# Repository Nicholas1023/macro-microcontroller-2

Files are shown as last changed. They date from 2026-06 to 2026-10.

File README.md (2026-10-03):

# Macro Microcontroller 2

An RP2040 microcontroller development board with an integrated macropad that lets you control GPIOs with keyboard keys on a single PCB, plus a custom BASIC interpreter and disk operating system.

Documentation page: <a href="https://nicholaslim.me/macro-microcontroller-2">https://nicholaslim.me/macro-microcontroller-2</a>

Hack Club Stardance Challenge project: <a href="https://stardance.hackclub.com/projects/21502">https://stardance.hackclub.com/projects/21502</a>

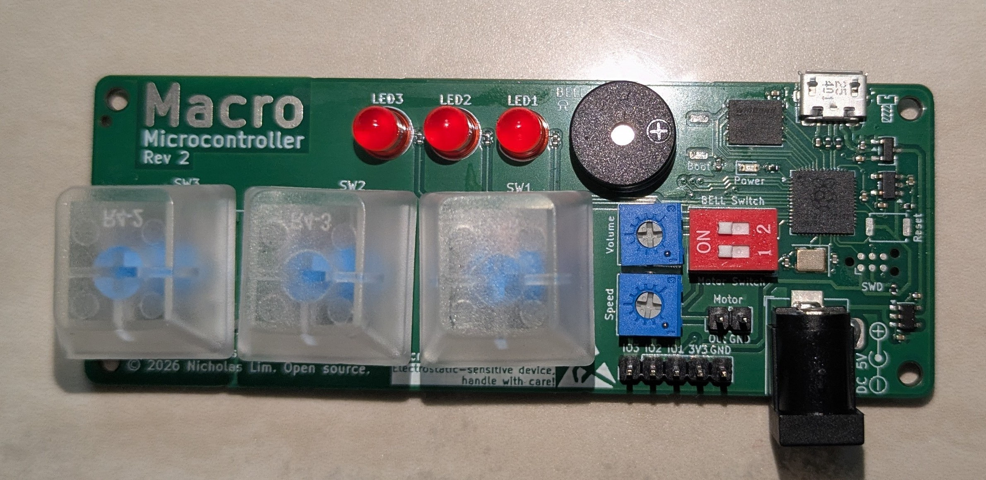
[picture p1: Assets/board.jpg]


View hardware demonstration at <a href="https://nicholaslim.me/macro-microcontroller-2/assets/hardware-demo.mp4">https://nicholaslim.me/macro-microcontroller-2/assets/hardware-demo.mp4</a>!

## What's New?
1. Microcontroller unit directly soldered on board!
2. More output devices with speed and volume adjustments (Buzzer and motor).
3. More ways to power the board (Barrel jack, USB, GPIO pins).
4. Custom BASIC interpreter and a disk operating system.

## What Does it Do?
Macro Microcontroller 2 allows you to control GPIO pins using macropad-like keys and from the serial terminal using the built-in <a href="Firmware Files/macro-microcontroller-basic.c">Macro Microcontroller BASIC Interpreter</a> or a <a href="Firmware Files/macro-microcontroller-bios+dos.c">disk operating system</a> for simple uses. It offers more ways to control GPIOs by having builtin keys that can be programmed to your own needs.

## Enclosure
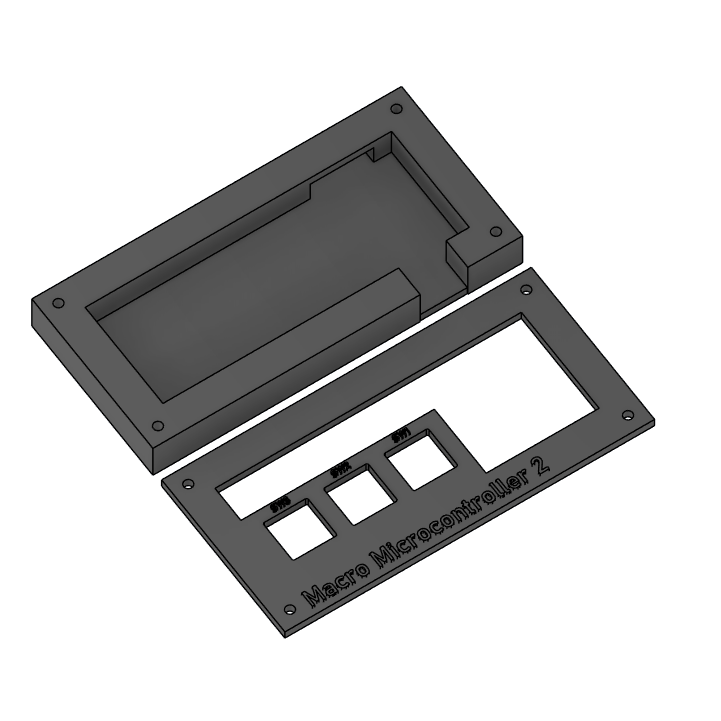
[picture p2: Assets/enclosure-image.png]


## Datasheet
For more details on the hardware, please read the <a href="docs/assets/macro-microcontroller-2-datasheet.pdf">datasheet</a>!

## Firmware
### Macro Microcontroller BIOS
A basic BIOS-like firmware, which performs basic POST routines and reports information on the device. <a href="Firmware Files/macro-microcontroller-bios.c">Source code</a>.
```
 _  _
| \/ | Macro Microcontroller BIOS Version 0.0.2.
|_\/_| Copyright (C) 2025-2026 Nicholas Lim.

Device: Macro Microcontroller 2 (RP2040 @ 125MHz)
Serial Number: ****************
RAM Free: 254K OK
Serial Status: Connected

Press SW1 to enter Macro Microcontroller BASIC.
Press SW2 to enter BOOTSEL mode.

Booting system...
```

### Macro Microcontroller DOS
A simple DOS-like environment that boots from the BIOS. <a href="Firmware Files/macro-microcontroller-bios+dos.c">Source code</a>.

Available commands (* denotes optional parameters):
1. `HELP`: Launches the help guide.
2. `CALCULATE`: Performs basic operations on 2 numbers. Usage: `CALCULATE [Number] [+ - * / ^ root] [Number]`
3. `ECHO`: Echoes text.
4. `PROGLIST`: Show program listing.
5. `SYSTEM`: Starts another Macro Microcontroller DOS console.
6. `EXIT`: Stops all processes for power off.
7. `OUT`: Turns on a specified GPIO for 1 second. Usage: `OUT [LED# IO# BELL MOTOR]`
8. `VERSION`: Shows the release version.
9. `BOOT`: Reboots the system. Usage: `BOOT -m [BASIC BOOTSEL]*`
10. `DEVINFO`: Displays device and memory information.
11. `UPTIME`: Shows device uptime.

### Macro Microcontroller BASIC Interpreter
A BASIC interpreter written in C for Macro Microcontroller, providing a simple coding environment via a serial terminal. You may view a demo at <a href="Assets/firmware-demo.mp4">Assets/firmware-demo.mp4</a>.

Currently available statements:
1. `PRINT`: Outputs text to the serial terminal.
2. `LET`: Assigns a value (integer, float or string) to a variable (Only one variable is allowed for now).
3. `INPUT`: Assigns a value (integer, float or string) to a variable via user input.
4. `GPIO`: Turns on a specified GPIO pin for 1 second.
5. `LSVAR`: Outputs variable name and their value to the serial terminal.
6. `END`: Clears variable and reset line numbers.
7. `EXIT`: Puts the device into sleep/power off mode.
8. `KEY`: Pass GPIO controls to the macropad.
9. `REM`: Add comments to your program.

For example programs, see <a href="Firmware Files/example.bas">Firmware Files/example.bas</a>.
Try out the web editor at <a href="https://editor.nicholaslim.me/macro-microcontroller">https://editor.nicholaslim.me/macro-microcontroller</a>!

## Schematics


View PCB file at https://kicanvas.org/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!

## Repository Structure
```
main
 ├── /docs ← Documentation website and datasheet files are here
 ├── /Assets ← Images and videos are here
 │     └── /Journal ← Images for JOURNAL.md
 ├── /PCB Files ← .kicad_ files are here
 ├── /Production Files ← Gerber and BOM files are here
 ├── /Printing Files ← STLs are here
 ├── /Firmware Files ← Firmware files are here
 ├── JOURNAL.md ← Devlogs
 ├── README.md ← This file
 ├── LICENSE.txt ← License
 └── schematics.pdf ← Schematics
 ```

## Bill of Materials (Excluding DNP)
|Component|Ref Designator|Qty|Footprint|
|---|---|---|---|
|HMB1206-03|BZ1|1|Buzzer_12x9.5RM7.6|
|Capacitor 0.1uF|C1, C2, C3, C4, C5, C6, C7, C10, C11|9|0402|
|Capacitor 8pF|C8, C9|2|0402|
|THT LED|D1, D2, D3|3|LED_D5.0mm|
|SMD LED|D4|1|0603|
|USB-B Micro Port|J1|1|USB_Micro-B_Molex_47346-0001|
|Barrel Jack|J3|1|BarrelJack_Horizontal|
|2.54 1x05 Pin|J4|1|PinHeader_1x05_P2.54mm_Vertical|
|2.54 1x02 Pin|M1|1|PinHeader_1x02_P2.54mm_Vertical|
|Resistor 27ohm|R1, R6|2|0402|
|Resistor 220ohm|R2, R4, R5, R7|4|0402|
|Resistor 5kohm|R3, R8, R9|3|0402|
|Potentiometer|RV1, RV2|2|Potentiometer_Vishay_T73YP_Vertical|
|Cherry MX Keys|SW1, SW2, SW3|3|SW_Cherry_MX_1.00u_PCB|
|Reset & Boot Button|SW4, SW6|2|SW_Push_SPST_NO_Alps_SKRK|
|DIP Switch|SW5|1|SW_DIP_SPSTx02_Slide_9.78x7.26mm_W7.62mm_P2.54mm|
|RP2040|U1|1|QFN-56-1EP_7x7mm_P0.4mm_EP3.2x3.2mm|
|TLV71311PDBVR|U2|1|SOT-23-5|
|XC6206P332MR|U3|1|SOT-23-3|
|W25Q128JVP|U4|1|WSON-8-1EP_6x5mm_P1.27mm_EP3.4x4.3mm|
|TPS76350|U6|1|SOT-23-5|
|NX3225SA-12MHz|Y1|1|Crystal_SMD_3225-4Pin_3.2x2.5mm|

## Legal
<b>Hardware files</b> ("<a href="PCB Files">PCB Files</a>", "<a href="Printing Files">Printing Files</a>", "<a href="Production Files">Production Files</a>", "<a href="schematics.pdf">schematics.pdf</a>") are licensed under the terms of the CERN-OHL-W-2.0 License from 9 September 2026 onwards. Versions prior to this date remain available under the terms of the CERN-OHL-P-2.0 License. See <a href="LICENSE.txt">LICENSE.txt</a>.

<b>Documentation files</b> ("<a href="docs">docs</a>", "<a href="Assets">Assets</a>", "<a href="JOURNAL.md">JOURNAL.md</a>") are licensed under the terms of the MIT License. See <a href="docs/LICENSE.txt">docs/LICENSE.txt</a>.

<a href="Firmware Files/macro-microcontroller-basic.c">macro-microcontroller-basic.c</a>, <a href="Firmware Files/macro-microcontroller-bios.c">macro-microcontroller-bios.c</a>, <a href="Firmware Files/macro-microcontroller-bios+dos.c">macro-microcontroller-bios+dos.c</a> are licensed under the terms of the MIT License. <a href="Firmware Files/firmware-template.c">firmware-template.c</a> is licensed under the terms of the MIT-0 License. <a href="Firmware Files/example.bas">example.bas</a> is marked <a href="https://creativecommons.org/publicdomain/zero/1.0/">CC0 1.0</a>.

Macro Microcontroller BIOS, Macro Microcontroller DOS and Macro Microcontroller BASIC compile source code from the following third-party software:

- Pico SDK: See <a href="Firmware Files/pico_sdk_import.cmake">Firmware Files/pico_sdk_import.cmake</a> for the Pico SDK license and copyright notice.

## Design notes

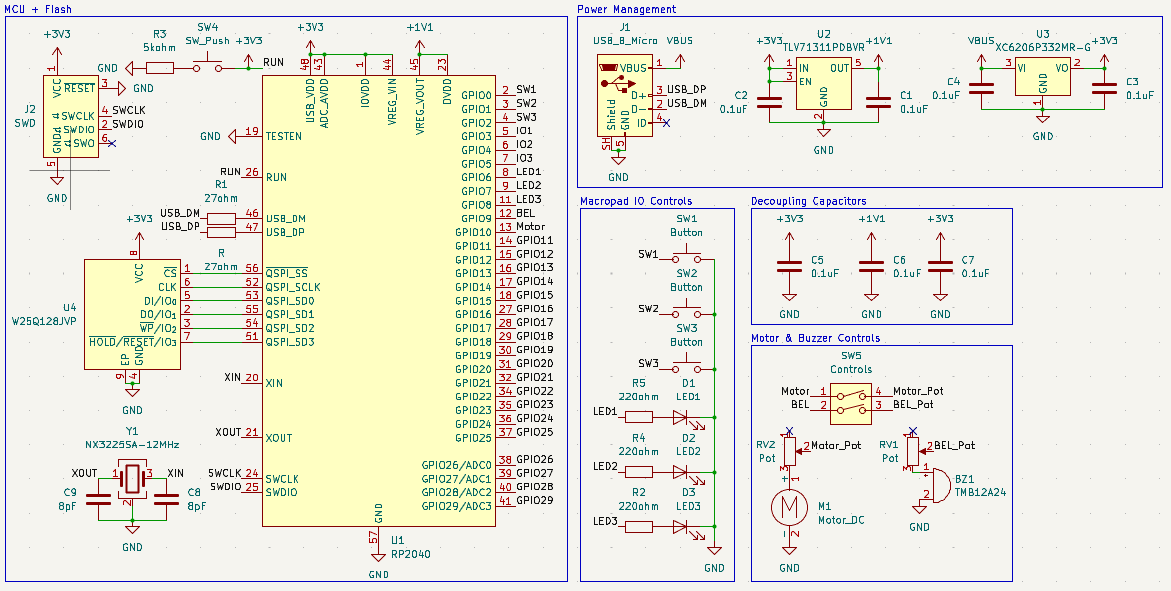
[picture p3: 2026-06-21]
Assets/Journal/schematics 2026-06-18.png

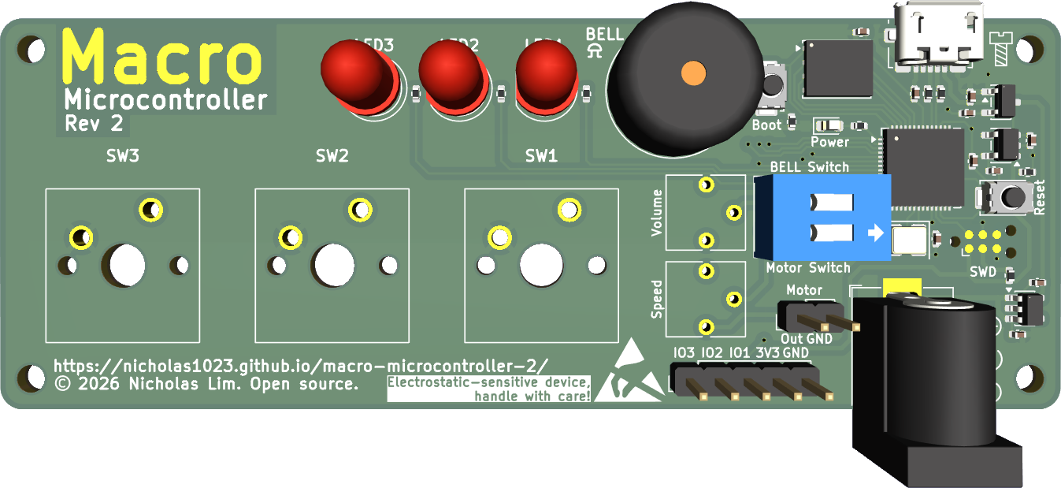
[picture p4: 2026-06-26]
Assets/macro-microcontroller-2.png

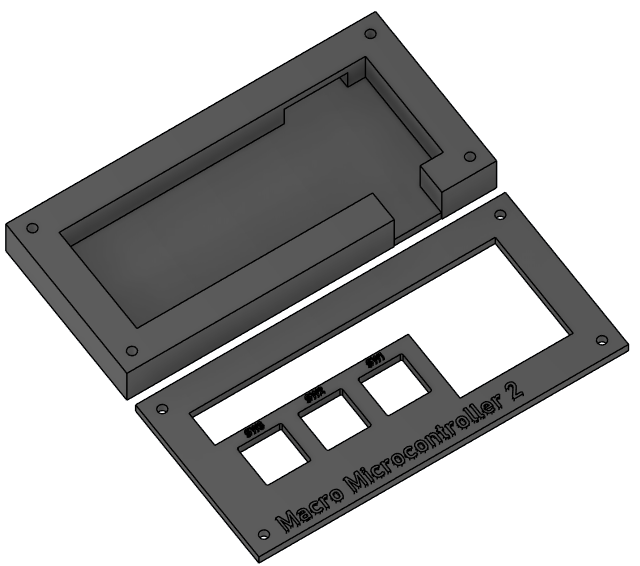
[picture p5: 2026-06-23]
docs/assets/enclosure-image.png

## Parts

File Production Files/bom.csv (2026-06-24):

Designator | Footprint | Quantity | Value | LCSC Part #
BZ1 | Buzzer_12x9.5RM7.6 | 1 | HMB1206-03 | C96101
C1, C10, C11, C2, C3, C4, C5, C6, C7 | 0402 | 9 | 0.1uF | C1525
C8, C9 | 0402 | 2 | 8pF | C1578
D1 | LED_D5.0mm | 1 | LED1 | C87271
D2 | LED_D5.0mm | 1 | LED2 | C87271
D3 | LED_D5.0mm | 1 | LED3 | C87271
D4 | 0603 | 1 | LED | C84266
J1 | USB_Micro-B_Molex_47346-0001 | 1 | USB_B_Micro | C132560
J3 | BarrelJack_Horizontal | 1 | Barrel_Jack_MountingPin | C16214
J4 | PinHeader_1x05_P2.54mm_Vertical | 1 | GPIO | C5156614
M1 | PinHeader_1x02_P2.54mm_Vertical | 1 | Motor_DC | C2905434
R1, R6 | 0402 | 2 | 27ohm | C25156
R2, R4, R5, R7 | 0402 | 4 | 220ohm | C25091
R3, R8, R9 | 0402 | 3 | 5kohm | C5948099
RV1, RV2 | Potentiometer_Vishay_T73YP_Vertical | 2 | Pot | C6278770
SW1, SW2, SW3 | SW_Cherry_MX_1.00u_PCB | 3 | Button
SW4 | SW_Push_SPST_NO_Alps_SKRK | 1 | Reset | C115357
SW5 | SW_DIP_SPSTx02_Slide_9.78x7.26mm_W7.62mm_P2.54mm | 1 | Controls | C92646
SW6 | SW_Push_SPST_NO_Alps_SKRK | 1 | Boot | C115357
U1 | QFN-56-1EP_7x7mm_P0.4mm_EP3.2x3.2mm | 1 | RP2040 | C2040
U2 | SOT-23-5 | 1 | TLV71311PDBVR | C205964
U3 | SOT-23-3 | 1 | XC6206P332MR | C5148692
U4 | WSON-8-1EP_6x5mm_P1.27mm_EP3.4x4.3mm | 1 | W25Q128JVP | C190862
U6 | SOT-23-5 | 1 | TPS76350 | C194609
Y1 | Crystal_SMD_3225-4Pin_3.2x2.5mm | 1 | NX3225SA-12MHz | C481400

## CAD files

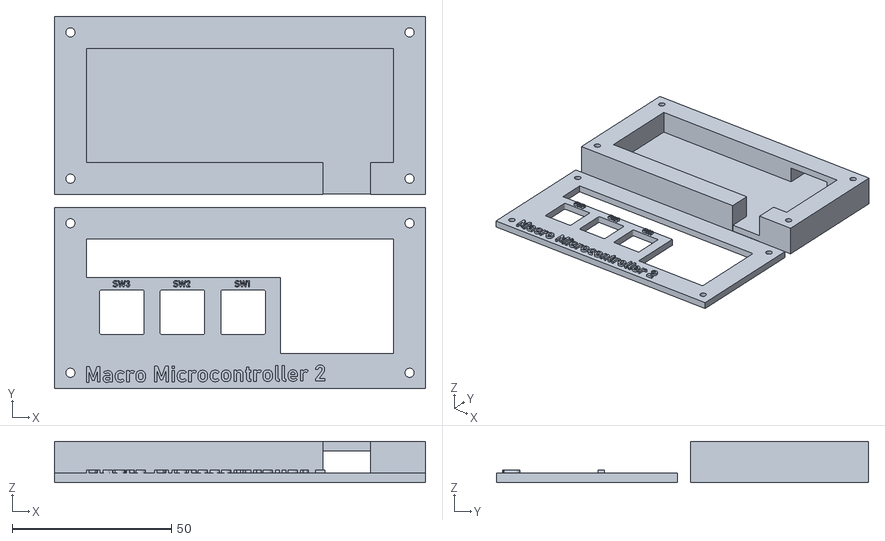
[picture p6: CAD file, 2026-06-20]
Printing Files/enclosure.stl
116.6 x 117.0 x 13.0

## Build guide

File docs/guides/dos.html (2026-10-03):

# Macro Microcontroller DOS Setup & Usage Guide

Macro Microcontroller DOS is a simple DOS-like environment that boots from a custom BIOS.

## Installation

1. First, download macro-microcontroller-dos-0.0.3.uf2 from releases (https://github.com/Nicholas1023/macro-microcontroller-2/releases/tag/Macro_Microcontroller_DOS_v0.0.3). Current version: 0.0.3
2. Next, plug in your development board while holding the Boot button. A storage drive will appear on your computer.
3. Move macro-microcontroller-dos-0.0.1.uf2 into the storage drive. Your development board is now running Macro Microcontroller DOS, booting from a custom BIOS!
4. Install a serial terminal application on your computer and connect it to the board. If successful, you should see the following:

 _  _
| \/ | Macro Microcontroller BIOS Version 0.0.2.
|_\/_| Copyright (C) 2025-2026 Nicholas Lim.

Device: Macro Microcontroller 2 (RP2040 @ 125MHz)
Serial Number: ****************
RAM Free: 254K OK
Serial Status: Connected

Press SW1 to enter Macro Microcontroller BASIC.
Press SW2 to enter BOOTSEL mode.

Booting system...

## Commands and Programs

- HELP: Launches the help guide.
- CALCULATE: Performs basic operations on 2 numbers. Usage: CALCULATE [Number] [+ - * / ^ root] [Number]
- ECHO: Echoes text.
- PROGLIST: Show program listing.
- SYSTEM: Starts another Macro Microcontroller DOS console.
- EXIT: Stops all processes for power off.
- OUT: Turns on a specified GPIO for 1 second. Usage: OUT [LED# IO# BELL MOTOR]
- VERSION: Shows the release version.
- BOOT: Reboots the system. Usage: BOOT -m [BASIC BOOTSEL]*
- DEVINFO: Displays device and memory information.
- UPTIME: Shows device uptime.

## Predefined Values for Parameters

- IO*: Set GPIO pins 1, 2 or 3 to high.
- LED*: Set LEDs 1, 2 or 3 to high.
- BELL: Sounds the builtin buzzer.
- MOTOR: Sets motor pins to high.
- BASIC: Reboot in BASIC interpreter mode.
- BOOTSEL: Reboot in BOOTSEL mode.

© 2026 Nicholas Lim. | Documentation licensed under MIT License (https://github.com/Nicholas1023/macro-microcontroller-2/blob/main/docs/LICENSE.txt). | Hardware licensed under CERN-OHL-W-2.0 License (https://github.com/Nicholas1023/macro-microcontroller-2/blob/main/LICENSE.txt).

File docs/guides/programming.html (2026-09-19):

# Macro Microcontroller BASIC Setup & Programming Guide

Macro Microcontroller BASIC is an interpreter based on the BASIC language for microcontroller development boards, specifically the Macro Microcontroller.

## Installation

1. First, download macro-microcontroller-basic-0.0.3.uf2 from releases (https://github.com/Nicholas1023/macro-microcontroller-2/releases/tag/v0.0.3). Current version: 0.0.3
2. Next, plug in your development board while holding the Boot button. A storage drive will appear on your computer.
3. Move macro-microcontroller-basic-0.0.3.uf2 into the storage drive. Your development board is now running Macro Microcontroller BASIC!
4. Install a serial terminal application on your computer and connect it to the board. If successful, you should see the following:

Macro Microcontroller BASIC Version 0.0.3.
Copyright (C) 2025-2026 Nicholas Lim.
521928 bytes of RAM free.
Ready.
10
  If not, try sending PRINT "It works!". If "It works!" is sent back to the serial terminal, you have successfully installed Macro Microcontroller BASIC.

## Syntax

Macro Microcontroller BASIC's syntax is similar to most other versions of BASIC:

10 <STATEMENT> <VALUE/ASSIGNMENT> Note: Line numbers are automatically appended by the interpreter.

## Statements

- PRINT: Outputs text to the serial terminal.
- LET: Assigns a value (integer, float or string) to a variable.
- INPUT: Assigns a value (integer, float or string) to a variable via user input.
- GPIO: Turns on a specified GPIO pin for 1 second.
- LSVAR: Outputs variable name and their value to the serial terminal.
- END: Clears variable and reset line numbers.
- EXIT: Puts the device into sleep/power off mode.
- KEY: Pass GPIO controls to the macropad.
- REM: Add comments to your program.

## Predefined Values

- IO*: Set GPIO pins 1, 2 or 3 to high.
- LED*: Set LEDs 1, 2 or 3 to high.
- BELL: Sounds the builtin buzzer.
- MOTOR: Sets motor pins to high.
- RND: Generates a random floating-point integer less than 1.

## Example Programs

Note: line numbers are automatically appended, hence there is no need to add them.

- Example 1: Hello world!

PRINT "hello world!"
END
- Example 2: Activate buzzer and motor

GPIO BELL
GPIO MOTOR
END
- Example 3: Random floating-point number

PRINT RND
END
- Example 4: Assigning variables

LET X = 5
LSVAR
END
- Example 5: Reading input

INPUT Name
PRINT "Hello, "
PRINT Name
END

© 2026 Nicholas Lim. | Documentation licensed under MIT License (https://github.com/Nicholas1023/macro-microcontroller-2/blob/main/docs/LICENSE.txt). | Hardware licensed under CERN-OHL-W-2.0 License (https://github.com/Nicholas1023/macro-microcontroller-2/blob/main/LICENSE.txt).

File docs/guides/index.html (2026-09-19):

# Macro Microcontroller 2 Guides

- Macro Microcontroller BASIC Setup & Programming Guide
- Macro Microcontroller DOS Setup & Usage Guide
- Macro Microcontroller 2 Datasheet

© 2026 Nicholas Lim. | Documentation licensed under MIT License (https://github.com/Nicholas1023/macro-microcontroller-2/blob/main/docs/LICENSE.txt). | Hardware licensed under CERN-OHL-W-2.0 License (https://github.com/Nicholas1023/macro-microcontroller-2/blob/main/LICENSE.txt).

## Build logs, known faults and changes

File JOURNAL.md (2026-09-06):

### Devlogs from <a href="https://stardance.hackclub.com/projects/21502">https://stardance.hackclub.com/projects/21502</a>

## New Commands for DOS!
### 6 September 2026, 2h 25m 38s

In this devlog, I added new commands for my OS:

- `CALCULATE`: Performs basic operations on 2 numbers. Usage: `CALCULATE [Number] [+ - * / ^ sqrt] [Number]`
- `GPIO`: Turns on a specified GPIO for 1 second. Usage: `GPIO [LED# IO# BELL MOTOR]`
- `VERSION`: Shows the release version.
- `REBOOT`: Reboots the system. Usage: `REBOOT -m [BASIC BOOTSEL]*`
- `INFO`: Displays device and memory information.
- `UPTIME`: Shows device uptime.

I took quite a while to find out how to make the `CALCULATE` command work. Initially, 1/3 was returning 0. Turns out the problem was due to me using integers instead of doubles!

Here's a demo video of the OS!

## Some updates to the documentation site!
### 2 September 2026, 30m 21s

Since I added a new firmware, I have to update the downloads section of my site! It took me quite a while to organise my repo a little bit, as the firmware files were getting a little messier and releases getting more complicated as I have 2 firmware now!

Next, I’ll be working on the DOS, adding more commands to the system!

## New firmware update!
### 2 September 2026, 4h 6m 46s

Previously, I was asking myself: How can I make my device look more like an old computer?

When I was turning on an old desktop I have at home, I saw the BIOS screen due to CMOS errors, and this was where I got an inspiration for a new firmware update.

In this devlog, I redid the firmware, added a BIOS-like CLI, while still keeping the original BASIC interpreter as a fallback if no bootable "OS" was found. Here's what it looks like:
```
 _  _
| \/ | Macro Microcontroller BIOS Version 0.0.1.
|_\/_| Copyright (C) 2025-2026 Nicholas Lim.

Device: Macro Microcontroller 2 (RP2040 @ 125MHz)
Serial Number: ************
RAM Free: 254K OK
Serial Status: Connected

Press SW1 to enter Macro Microcontroller BASIC.
Press SW2 to enter BOOTSEL mode.

Booting system...
```

The UI was inspired by the old BIOS POST screens from the 1980s. As I wanted a retro feel to my microcontroller, I thought that a BIOS-like system would look nice to it!

Thanks for reading!

## Finally received the board and soldered the parts on!
### 11 July 2026, 3h 40m 21s

In this devlog, I made some changes to the firmware and released v0.0.3 that adds support for comments:
```basic
10 REM This is a comment that will be ignored!
20 PRINT "Hello world!"
```
I've also added a more detailed [programming guide](https://nicholas1023.github.io/macro-microcontroller-2/programming.html) for my custom BASIC Interpreter.

## Difficulties I've faced
I had some trouble soldering the keyboard switches on as it was moving everywhere. I've attempted applying tape, but it did not work as the temperature was too high. 

I'll be tidying up the repo and get ready to finally ship🚢 my project!

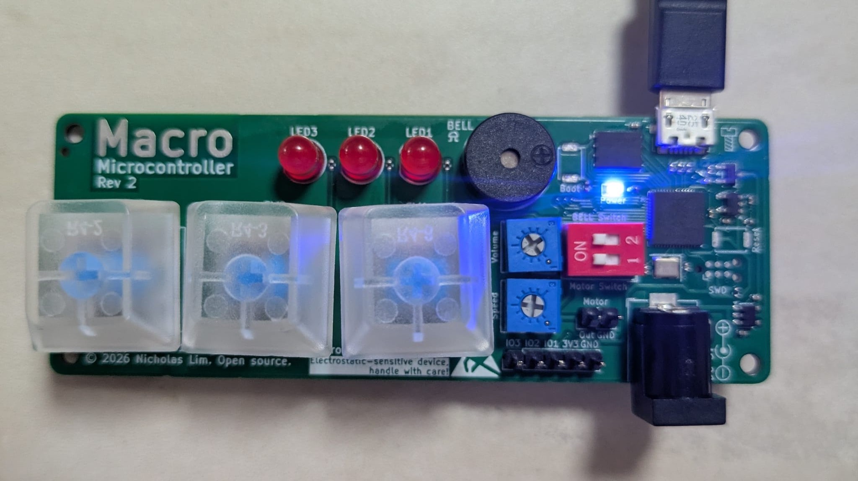
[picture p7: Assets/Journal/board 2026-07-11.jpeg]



## Updated the firmware and ordered my PCB and parts!
### 3 July 2026, 2h 55m 43s
In this devlog, I've added a new function to my custom BASIC interpreter for my development board, and finally sent my PCB for manufacturing!

It took me quite a while to write the random number function that the old BASIC interpreters used to have: `RND`. I did many rounds of trial and error to finally create a working code (the previous code was returning either nothing or throwing compiler errors due to data types):
```c
printf("%f\n", (float)rand() / (float)RAND_MAX);
```
Here's a sample program you could run that generates a random number, stores it in a variable and prints it:
```basic
10 let x = rnd
20 lsvar
30 print x
```
Now, I'll be working on support for comments in my interpreter and wait for my parts to come. I can't wait to assemble my macropad + dev board!

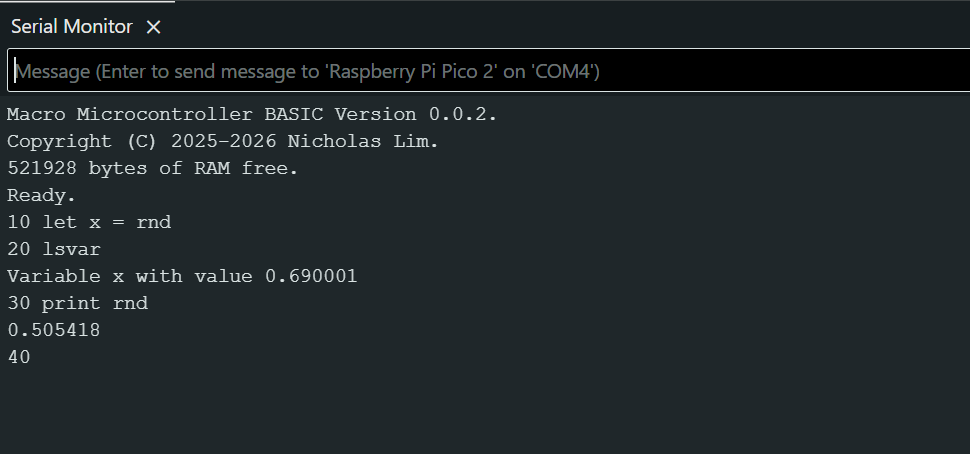
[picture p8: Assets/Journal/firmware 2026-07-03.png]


## More updates to the documentation site!
### 24 June 2026, 1h 15m 23s
Today, I changed the layout and content of the documentation website and made it responsive for mobile devices! I initially wanted to add a 3D viewer to display the `.glb` file for rendering, but it did not output the result I wanted. (The silkscreen was not appearing!) I’ll read up on more about it, and hopefully, I would be able to add the 3D model into my documentation!

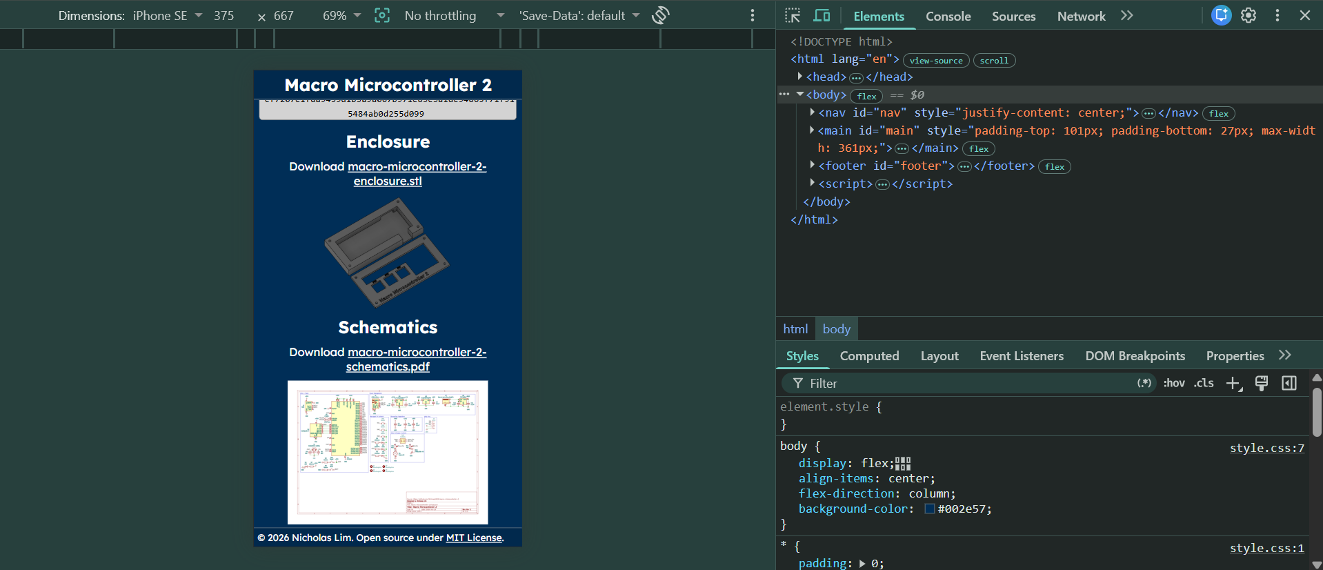
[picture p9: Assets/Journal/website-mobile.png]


## Created a documentation site for my microcontroller!
### 23 June 2026, 2h 35m 8s
In this devlog, I improved the documentation of my project by creating a simple website to share specifications, schematics, and provide a direct link to download firmware and 3D print files. You may view it at <a href="https://nicholas1023.github.io/macro-microcontroller-2">https://nicholas1023.github.io/macro-microcontroller-2</a>!

### What I’ll be doing next
Next, I will be ordering the PCB and electronic components and finally solder them together!

<image src="Assets/Journal/macro-microcontroller-website.webp">

## Finished the enclosure and organised the repository!
### 20 June 2026, 3h 1m 11s
Today, I have completed the 3D case for Macro Controller 2 and did some minor bug fixes for the BASIC Interpreter. I needed to reassign the GPIO pins from the first revision of the board.

Although the interpreter is currently still basic, it supports 4 BASIC statements and 4 custom statements for controls.

### What’s new in this devlog
- Text and key labels for enclosure with cover
- Organised repository
- New `KEY` statement for hardware GPIO control

<b><a href="Assets/firmware-demo.mp4">Firmware demonstration video</a></b>

<image src="Assets/macro-microcontroller-2.png">
<image src="Assets/enclosure-image.png">

## Halfway through my PCB's case!
### 19 June 2026, 2h 4m 14s

### What I've done in this devlog
For the first-half, I added silkscreen text to the PCB for the IO components (GPIO Pins, Keyboard switches, LEDs...). Next, I moved on to designing the enclosure. It took a while for me to get used to using a new app to design it.

### Modifications to the PCB
- Added screw mounting pads for easier mounting.
- LEDs moved closer to each other for space to add silkscreen designs.

### Problems I've faced
The screw holes were not appearing during the first few attempts, but it worked in the end when I placed it manually, instead of using the move function.

Creating the cutout for the USB connector took me about 15 mins as I needed to measure the length and clearance needed for a micro-USB plug and create another sketch before extruding it as a cutout.

### What I'll be working on next
Next, I'll be continuing with the enclosure design, adding a cover with a keyboard plate, and finally moving on to the BASIC interpreter firmware for it!

<image src="Assets/macro-microcontroller-2.png">
<image src="Assets/Journal/enclosure 2026-06-19.png">

## Finished routing my microcontroller board!
### 19 June 2026, 2h 1m 39s

Did most of the routing for the MCU and macropad segment today, but I might need to do some rewiring for the flash memory as the trace length for `SD0` and `SD2` are very different (5.57 & 13.2 mm).

### What has been added since the last devlog
- Added power LED
- Added pin headers for GPIO and power
- Added barrel jack in case if the DC motor drains too much power

### What I'll be doing next
Next, I'll be adding more silkscreen text, and maybe design an icon for my macropad + microcontroller board. I'll also be creating a custom enclosure for my device!

<image src="Assets/Journal/PCB 2026-06-19.png">

## Finished the schematics and a little of the BASIC Interpreter for my microcontroller board! 
### 18 June 2026, 2h 22m 57s

### What I did today
- Redid the old schematics by adding custom RP2040 circuit instead of a using a dev board.
- Added new GPIO devices such as DC motor and a buzzer. (for the BASIC interpreter)
- Started on `PRINT`, `LET` and `INPUT` for the interpreter.

### What I'll be doing next
Next, I will be focusing on the BASIC interpreter firmware, working on variable assignment and math operations and testing it on a real pico board! Also, I will be starting on the layout and BOM as I have completed the schematics!

<image src="Assets/Journal/schematics 2026-06-18.png">

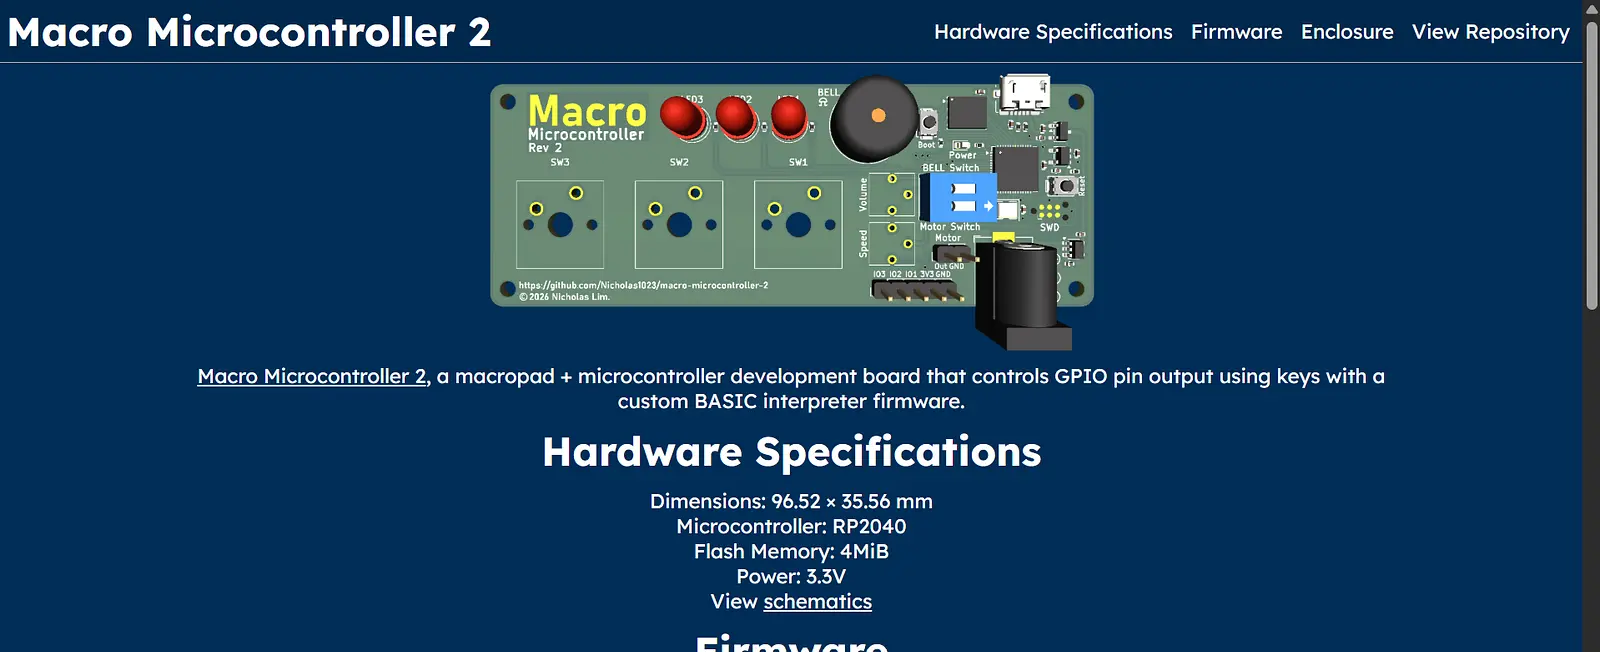
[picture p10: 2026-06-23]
Assets/Journal/macro-microcontroller-website.webp

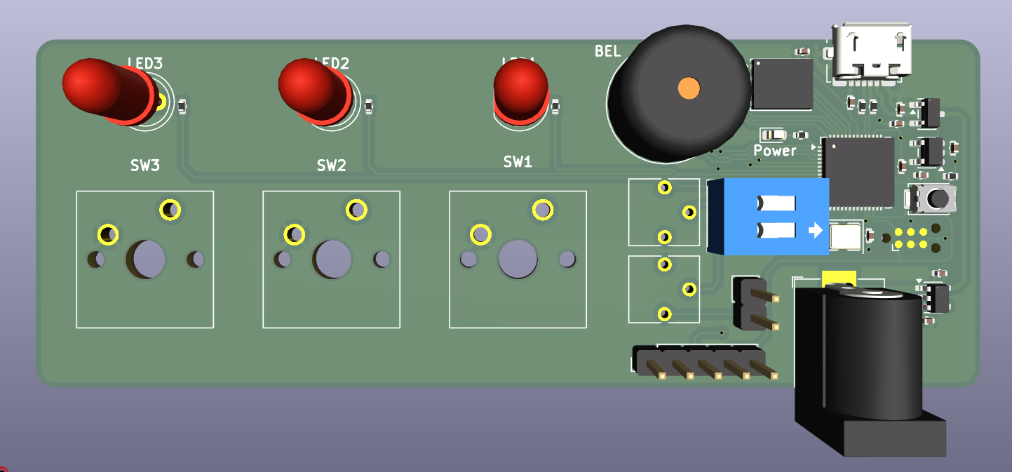
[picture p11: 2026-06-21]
Assets/Journal/PCB 2026-06-19.png

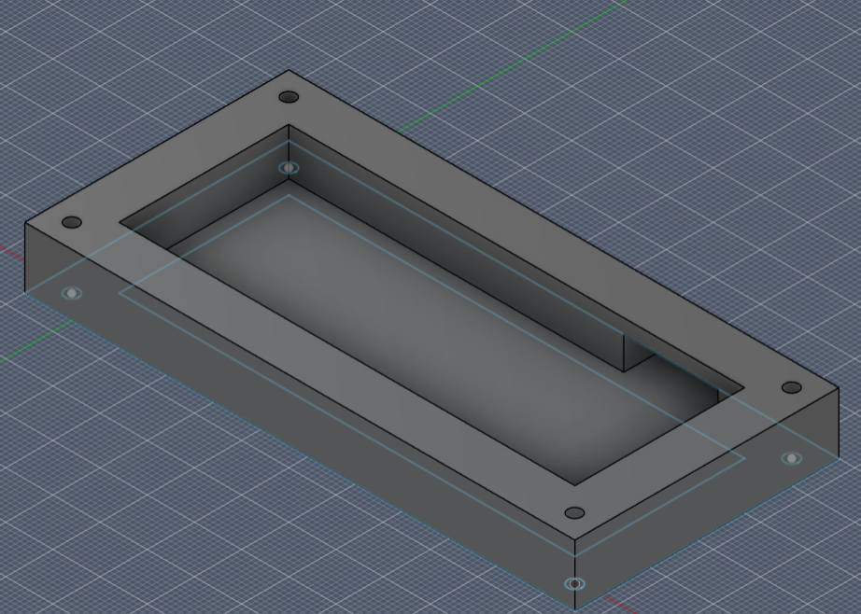
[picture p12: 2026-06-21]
Assets/Journal/enclosure 2026-06-19.png

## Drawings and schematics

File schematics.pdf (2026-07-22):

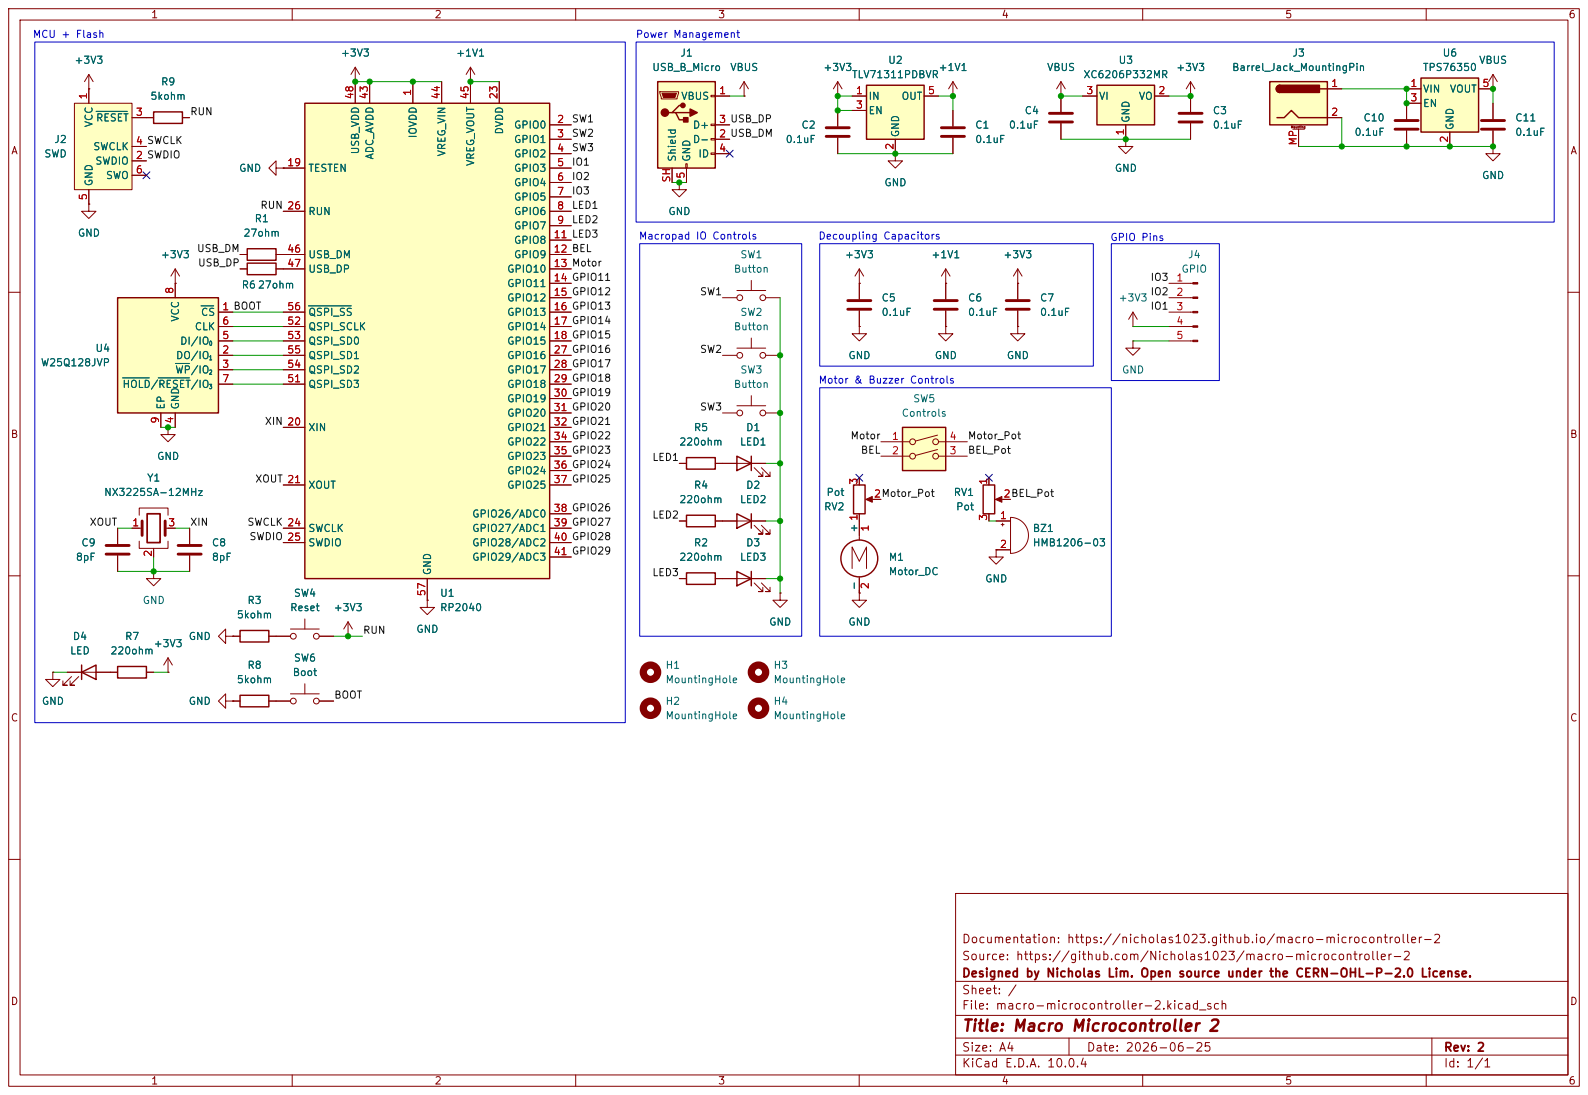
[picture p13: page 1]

4 DI/IO0 5 CLK 6 HOLD/RESET/IO3 7 VCC

Documentation: https://nicholas1023.github.io/macro-microcontroller-2
Source: https://github.com/Nicholas1023/macro-microcontroller-2
Designed by Nicholas Lim. Open source under the CERN-OHL-P-2.0 License.
Sheet: /
File: macro-microcontroller-2.kicad_sch
Title: Macro Microcontroller 2

Size: A4 | Rev: 2
KiCad E.D.A. 10.0.4 | Id: 1/1

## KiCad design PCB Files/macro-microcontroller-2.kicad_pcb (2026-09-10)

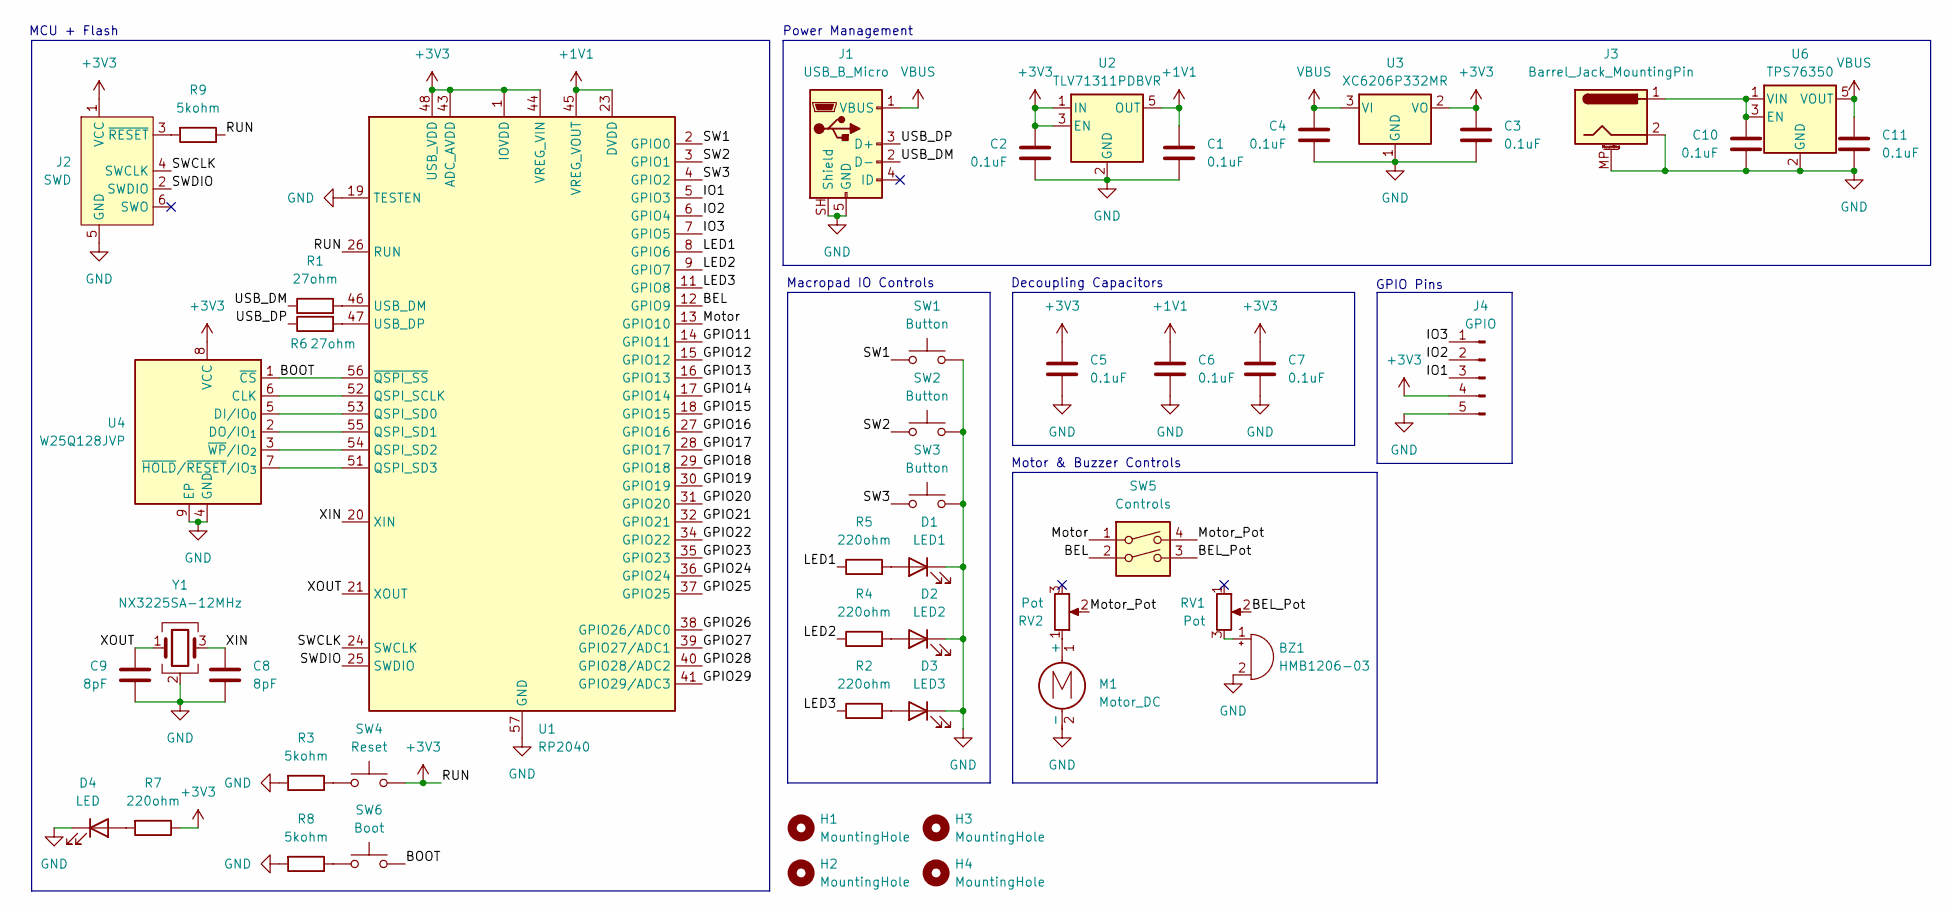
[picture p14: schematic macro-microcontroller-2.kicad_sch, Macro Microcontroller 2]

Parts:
BZ1: HMB1206-03; Buzzer_12x9.5RM7.6; LCSC C96101
C1, C2, C3, C4, C5, C6, C7, C10, C11: 0.1uF; C_0402_1005Metric; LCSC C1525
C8, C9: 8pF; C_0402_1005Metric; LCSC C1578
D1: LED1; LED_D5.0mm; LCSC C87271
D2: LED2; LED_D5.0mm; LCSC C87271
D3: LED3; LED_D5.0mm; LCSC C87271
D4: LED; LED_0603_1608Metric; LCSC C84266
H1, H2, H3, H4: MountingHole; MountingHole_2.5mm
J1: USB_B_Micro; USB_Micro-B_Molex_47346-0001; LCSC C132560
J2: SWD; Tag-Connect_TC2030-IDC-NL_2x03_P1.27mm_Vertical
J3: Barrel_Jack_MountingPin; BarrelJack_Horizontal; LCSC C16214
J4: GPIO; PinHeader_1x05_P2.54mm_Vertical; LCSC C5156614
M1: Motor_DC; PinHeader_1x02_P2.54mm_Vertical; LCSC C2905434
R1, R6: 27ohm; R_0402_1005Metric; LCSC C25156
R2, R4, R5, R7: 220ohm; R_0402_1005Metric; LCSC C25091
R3, R8, R9: 5kohm; R_0402_1005Metric; LCSC C5948099
RV1, RV2: Pot; Potentiometer_Vishay_T73YP_Vertical; LCSC C6278770
SW1, SW2, SW3: Button; SW_Cherry_MX_1.00u_PCB
SW4: Reset; SW_Push_SPST_NO_Alps_SKRK; LCSC C115357
SW5: Controls; SW_DIP_SPSTx02_Slide_9.78x7.26mm_W7.62mm_P2.54mm; LCSC C92646
SW6: Boot; SW_Push_SPST_NO_Alps_SKRK; LCSC C115357
U1: RP2040; QFN-56-1EP_7x7mm_P0.4mm_EP3.2x3.2mm; LCSC C2040
U2: TLV71311PDBVR; SOT-23-5; LCSC C205964
U3: XC6206P332MR; SOT-23-3; LCSC C5148692
U4: W25Q128JVP; WSON-8-1EP_6x5mm_P1.27mm_EP3.4x4.3mm; LCSC C190862
U6: TPS76350; SOT-23-5; LCSC C194609
Y1: NX3225SA-12MHz; Crystal_SMD_3225-4Pin_3.2x2.5mm; LCSC C481400

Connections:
+1V1: C1.1, C6.1, U1.23 (DVDD), U1.45 (VREG_VOUT), U1.50 (DVDD), U2.5 (OUT)
+3V3: C2.1, C3.1, C5.1, C7.1, J2.1 (VCC), J4.4, R7.1, R9.1, SW4.2, U1.1 (IOVDD), U1.10 (IOVDD), U1.22 (IOVDD), U1.26 (RUN), U1.33 (IOVDD), U1.42 (IOVDD), U1.43 (ADC_AVDD), U1.44 (VREG_VIN), U1.48 (USB_VDD), U1.49 (IOVDD), U2.1 (IN), U2.3 (EN), U3.2 (VO), U4.8 (VCC)
/BEL: SW5.2, U1.12 (GPIO9)
/BEL_Pot: RV1.2, SW5.3
/BOOT: SW6.2, U1.56 (~QSPI_SS), U4.1 (~CS)
/GPIO11: U1.14 (GPIO11)
/GPIO12: U1.15 (GPIO12)
/GPIO13: U1.16 (GPIO13)
/GPIO14: U1.17 (GPIO14)
/GPIO15: U1.18 (GPIO15)
/GPIO16: U1.27 (GPIO16)
/GPIO17: U1.28 (GPIO17)
/GPIO18: U1.29 (GPIO18)
/GPIO19: U1.30 (GPIO19)
/GPIO20: U1.31 (GPIO20)
/GPIO21: U1.32 (GPIO21)
/GPIO22: U1.34 (GPIO22)
/GPIO23: U1.35 (GPIO23)
/GPIO24: U1.36 (GPIO24)
/GPIO25: U1.37 (GPIO25)
/GPIO26: U1.38 (GPIO26/ADC0)
/GPIO27: U1.39 (GPIO27/ADC1)
/GPIO28: U1.40 (GPIO28/ADC2)
/GPIO29: U1.41 (GPIO29/ADC3)
/IO1: J4.3, U1.5 (GPIO3)
/IO2: J4.2, U1.6 (GPIO4)
/IO3: J4.1, U1.7 (GPIO5)
/LED1: R5.1, U1.8 (GPIO6)
/LED2: R4.1, U1.9 (GPIO7)
/LED3: R2.1, U1.11 (GPIO8)
/Motor: SW5.1, U1.13 (GPIO10)
/Motor_Pot: RV2.2, SW5.4
/SW1: SW1.1, U1.2 (GPIO0)
/SW2: SW2.1, U1.3 (GPIO1)
/SW3: SW3.1, U1.4 (GPIO2)
/SWCLK: J2.4 (SWCLK), U1.24 (SWCLK)
/SWDIO: J2.2 (SWDIO), U1.25 (SWDIO)
/USB_DM: J1.2 (D-), R1.1
/USB_DP: J1.3 (D+), R6.1
/XIN: C8.1, U1.20 (XIN), Y1.3
/XOUT: C9.1, U1.21 (XOUT), Y1.1
GND: BZ1.2 (-), C1.2, C2.2, C3.2, C4.2, C5.2, C6.2, C7.2, C8.2, C9.2, C10.2, C11.2, D1.1 (K), D2.1 (K), D3.1 (K), D4.1 (K), J1.5 (GND), J1.SH (Shield), J2.5 (GND), J3.2, J3.MP (MountPin), J4.5, M1.2 (-), R3.2, R8.2, SW1.2, SW2.2, SW3.2, U1.19 (TESTEN), U1.57 (GND), U2.2 (GND), U3.1 (GND), U4.4 (GND), U4.9 (EP), U6.2 (GND), Y1.2 (G), Y1.4 (G)
unnamed: BZ1.1 (+), RV1.3
unnamed: D1.2 (A), R5.2
unnamed: D2.2 (A), R4.2
unnamed: D3.2 (A), R2.2
unnamed: D4.2 (A), R7.2
unnamed: J2.3 (~RESET), R9.2
unnamed: M1.1 (+), RV2.1
unnamed: R3.1, SW4.1
unnamed: R8.1, SW6.1
unnamed: U1.52 (QSPI_SCLK), U4.6 (CLK)
unnamed: U1.53 (QSPI_SD0), U4.5 (DI/IO_{0})
unnamed: U1.55 (QSPI_SD1), U4.2 (DO/IO_{1})
unnamed: U1.54 (QSPI_SD2), U4.3 (~WP/IO_{2})
unnamed: U1.51 (QSPI_SD3), U4.7 (~HOLD/~RESET/IO_{3})
unnamed: R1.2, U1.46 (USB_DM)
unnamed: R6.2, U1.47 (USB_DP)
unnamed: C10.1, J3.1, U6.1 (VIN), U6.3 (EN)
VBUS: C4.1, C11.1, J1.1 (VBUS), U3.3 (VI), U6.5 (VOUT)

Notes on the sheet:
Macropad IO Controls
GPIO Pins
Power Management
Decoupling Capacitors
MCU + Flash
Motor & Buzzer Controls

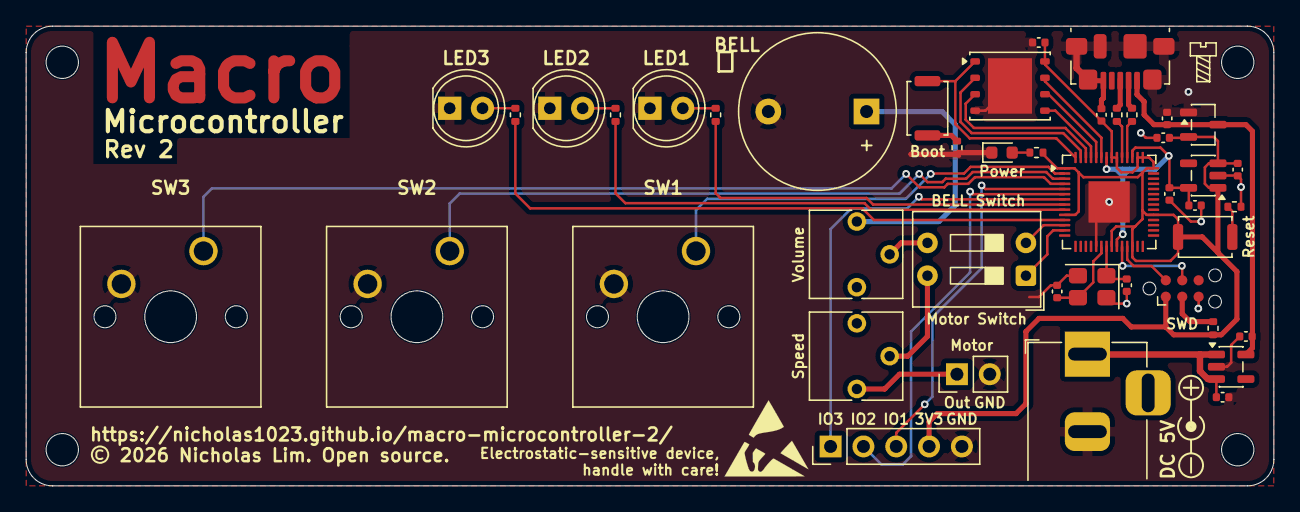
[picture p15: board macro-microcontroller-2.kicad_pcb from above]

Board: 2 copper layers, 96.5 x 35.6 mm, 48 parts (0 on the bottom side), 41 nets.

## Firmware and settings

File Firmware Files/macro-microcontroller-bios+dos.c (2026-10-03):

// SPDX-License-Identifier: MIT
// SPDX-FileCopyrightText: 2025-2026 Nicholas Lim <nicholas_lim@bbsshack.club>
/*
Macro Microcontroller BIOS + Macro Microcontroller DOS, Version 0.0.3.
PCB files for Macro Microcontroller 2 are available at
https://github.com/Nicholas1023/macro-microcontroller-2.

MIT License

Copyright (C) 2025-2026 Nicholas Lim.

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
THE SOFTWARE IS PROVIDED "AS IS", WITHOUT WARRANTY OF ANY KIND, EXPRESS OR
IMPLIED, INCLUDING BUT NOT LIMITED TO THE WARRANTIES OF MERCHANTABILITY,
FITNESS FOR A PARTICULAR PURPOSE AND NONINFRINGEMENT. IN NO EVENT SHALL THE
AUTHORS OR COPYRIGHT HOLDERS BE LIABLE FOR ANY CLAIM, DAMAGES OR OTHER
LIABILITY, WHETHER IN AN ACTION OF CONTRACT, TORT OR OTHERWISE, ARISING FROM,
OUT OF OR IN CONNECTION WITH THE SOFTWARE OR THE USE OR OTHER DEALINGS IN THE
SOFTWARE.
*/

#include <stdio.h>
#include <stdlib.h>
#include <string.h>
#include <math.h>
#include "pico/stdlib.h"
#include "pico/sync.h"
#include "pico/bootrom.h"
#include "pico/unique_id.h"
#include "hardware/clocks.h"
#include "hardware/flash.h"

extern char __flash_binary_end;

const int SW1 = 0;
const int SW2 = 1;
const int SW3 = 2;

const int IO1 = 3;
const int IO2 = 4;
const int IO3 = 5;

const int LED1 = 6;
const int LED2 = 7;
const int LED3 = 8;

const int BELL = 9;
const int MOTOR = 10;

extern char end;
bool lastSW1 = false;
bool lastSW2 = false;

char *variable[] = {"", ""};
char input[51];
char DOS_input[51];
char user_input[51];
char command[51];
int line_count = 0;
int mode = 0;

// Change the following to true to boot to Macro Microcontroller DOS.
bool userconfig = true;

void interpreter();
void blink();
void gpio_control();
void DOS();

int main() {
    stdio_init_all();
    gpio_init(SW1);
    gpio_init(SW2);
    gpio_init(SW3);
    gpio_init(IO1);
    gpio_init(IO2);
    gpio_init(IO3);
    gpio_init(LED1);
    gpio_init(LED2);
    gpio_init(LED3);
    gpio_init(BELL);
    gpio_init(MOTOR);
    gpio_set_dir(SW1, GPIO_IN);
    gpio_set_dir(SW2, GPIO_IN);
    gpio_set_dir(SW3, GPIO_IN);
    gpio_set_dir(LED1, GPIO_OUT);
    gpio_set_dir(LED2, GPIO_OUT);
    gpio_set_dir(LED3, GPIO_OUT);
    gpio_set_dir(BELL, GPIO_OUT);
    gpio_set_dir(MOTOR, GPIO_OUT);
    gpio_set_dir(IO1, GPIO_OUT);
    gpio_set_dir(IO2, GPIO_OUT);
    gpio_set_dir(IO3, GPIO_OUT);
    gpio_pull_up(SW1);
    gpio_pull_up(SW2);
    gpio_pull_up(SW3);
    sleep_ms(2000);
    printf(" _  _\n");
    printf("| \\/ | Macro Microcontroller BIOS Version 0.0.2.\n");
    printf("|_\\/_| Copyright (C) 2025-2026 Nicholas Lim.\n\n");
    printf("Device: Macro Microcontroller 2 (RP2040 @ %.0fMHz)\n", clock_get_hz(clk_sys)/1e+6);
    pico_unique_board_id_t id;
    pico_get_unique_board_id(&id);
    printf("Serial Number: ");
    for (int i = 0; i < PICO_UNIQUE_BOARD_ID_SIZE_BYTES; i++) {
        printf("%02X", id.id[i]);
    }
    volatile uint32_t stack_var;
    printf("\nRAM Free: %dK", ((uint32_t)&stack_var - (uint32_t)&end)/1024);
    int memTest = 1;
    if (memTest != 1) {
        gpio_put(BELL, 1);
        sleep_ms(100);
        gpio_put(BELL, 0);
        sleep_ms(100);
        gpio_put(BELL, 1);
        sleep_ms(100);
        gpio_put(BELL, 0);
        printf(" Error\nBIOS POST Failed. Restart your device to try again.\n");
        while (1) __wfi();
    }
    printf(" OK\nSerial Status: ");
    if (stdio_usb_connected()) {
        printf("Connected\n\n");
    } else {
        printf("Not connected\n\n");
    }
    gpio_put(BELL, 1);
    sleep_ms(100);
    gpio_put(BELL, 0);
    printf("Press SW1 to enter Macro Microcontroller BASIC.\nPress SW2 to enter BOOTSEL mode.\n\n");
    uint32_t startup = to_ms_since_boot(get_absolute_time());
    while (1) {
        bool currentSW1 = gpio_get(SW1);
        bool currentSW2 = gpio_get(SW2);
        uint32_t now = to_ms_since_boot(get_absolute_time());
        if (!currentSW1 && lastSW1 && now - startup <= 2000 || mode == 1) {
            sleep_ms(40);
            if (gpio_get(SW1)) {
                interpreter();
            }
        } if (!currentSW2 && lastSW2 && now - startup <= 2000 || mode == 2) {
            sleep_ms(40);
            if (gpio_get(SW2)) {
                printf("Entering BOOTSEL mode...\n");
                reset_usb_boot(0, 0);
            }
        } else if (now - startup > 1000) {
            break;
        }
        lastSW1 = currentSW1;
        lastSW2 = currentSW2;
    }
    printf("Booting system... ");
    sleep_ms(500);
    if (!userconfig) {
        gpio_put(BELL, 1);
        sleep_ms(500);
        gpio_put(BELL, 0);
        printf("No bootable media found.\n");
        
    } else {
        printf("\n\n");
        DOS();
    }
    printf("Stopping all system processes... You may turn off your device now.");
    while (1) __wfi();
}

void DOS() {
    printf("Macro Microcontroller Disk Operating System Version 0.0.3.\nCopyright (C) 2026 Nicholas Lim.\n");
    while (true) {;
        printf("Drive A> ");
        memset(DOS_input, 0, 51);
        fgets(DOS_input, 51, stdin);
        printf("%s", DOS_input);
        char *DOS_statement = strtok(DOS_input, " ");
        if (DOS_statement == NULL) continue;
        if (strcasecmp(DOS_statement, "ECHO") == 0 || strcasecmp(DOS_statement, "ECHO.PROG") == 0) {
            DOS_statement = strtok(NULL, "\n");
            if (DOS_statement == NULL) continue;
            printf("%s\n", DOS_statement);

        } else if (strcasecmp(DOS_statement, "HELP\n") == 0 || strcasecmp(DOS_statement, "HELP.PROG\n") == 0) {
            printf("Macro Microcontroller DOS Help Guide\nAvailable commands (* denotes optional parameters):\n- HELP: Launches the help guide.\n- CALCULATE: Performs basic operations on 2 numbers. Usage: CALCULATE [Number] [+ - * / ^ root] [Number]\n- ECHO: Echoes text.\n- PROGLIST: Show program listing.\n- SYSTEM: Starts another Macro Microcontroller DOS console.\n- EXIT: Stops all processes for power off.\n- OUT: Turns on a specified GPIO for 1 second. Usage: OUT [LED# IO# BELL MOTOR]\n- VERSION: Shows the release version.\n- BOOT: Reboots the system. Usage: BOOT -m [BASIC BOOTSEL]*\n- DEVINFO: Displays device and memory information.\n- UPTIME: Shows device uptime.\n");
        
        } else if (strcasecmp(DOS_statement, "PROGLIST\n") == 0 || strcasecmp(DOS_statement, "PROGLIST.PROG") == 0) {
            uint32_t free_flash = (16 * 1024 * 1024) - (((uintptr_t)&__flash_binary_end) - XIP_BASE);
            printf("Storage: %uMB free\nProgram listing of Drive A:\nName             Last modified\n──────────────────────────────────\nSYSTEM.PROG      03-10-2026 13:50\nHELP.PROG        06-09-2026 10:21\nCALCULATE.PROG   06-09-2026 09:22\nBOOT.PROG        03-10-2026 11:47\nECHO.PROG        06-09-2026 09:01\nPROGLIST.PROG    03-10-2026 11:45\nVERSION.PROG     06-09-2026 09:30\nOUT.PROG         03-10-2026 11:45\nDEVINFO.PROG     03-10-2026 11:45\nUPTIME.PROG      06-09-2026 10:23\n──────────────────────────────────\n", free_flash / 1024 / 1024);
        
        } else if (strcasecmp(DOS_statement, "SYSTEM\n") == 0 || strcasecmp(DOS_statement, "SYSTEM.PROG\n") == 0) {
            DOS();
        
        } else if (strcasecmp(DOS_statement, "VERSION\n") == 0 || strcasecmp(DOS_statement, "VERSION.PROG\n") == 0) {
            printf("Macro Microcontroller Disk Operating System Version 0.0.3 Release 10-03-2026.\nCopyright (C) 2026 Nicholas Lim. Open source under the MIT License.\nView source at https://github.com/Nicholas1023/macro-microcontroller-2.\n");
        
        } else if (strcasecmp(DOS_statement, "DEVINFO\n") == 0 || strcasecmp(DOS_statement, "DEVINFO.PROG\n") == 0) {
            printf("Device: Macro Microcontroller 2\nProcessor: RP2040 @ %.0fMHz\n", clock_get_hz(clk_sys)/1e+6);
            pico_unique_board_id_t id;
            pico_get_unique_board_id(&id);
            printf("Serial Number: ");
            for (int i = 0; i < PICO_UNIQUE_BOARD_ID_SIZE_BYTES; i++) {
                printf("%02X", id.id[i]);
            }
            volatile uint32_t stack_var;
            printf("\nRAM Free: %dKB\n", ((uint32_t)&stack_var - (uint32_t)&end)/1024);
            uint32_t free_flash = (16 * 1024 * 1024) - (((uintptr_t)&__flash_binary_end) - XIP_BASE);
            printf("Flash Free: %uMB\n", free_flash / 1024 / 1024);
        
        } else if (strcasecmp(DOS_statement, "CALCULATE\n") == 0 || strcasecmp(DOS_statement, "CALCULATE.PROG\n") == 0) {
            printf("Error: Missing parameters.\n");
        
        } else if (strcasecmp(DOS_statement, "CALCULATE") == 0 || strcasecmp(DOS_statement, "CALCULATE.PROG") == 0) {
            char *calc[3];
            for (int i=0; i<3; i++){
                DOS_statement = strtok(NULL, " ");
                if (DOS_statement != NULL) {
                    calc[i] = strdup(DOS_statement);
                } else {
                    printf("Error: Missing parameters.\n");
                    break;
                }
            }
            double a = atof(calc[0]);
            double b = atof(calc[2]);
            if (strcmp(calc[1], "+") == 0) {
                printf("%g", a + b);
            } else if (strcmp(calc[1], "-") == 0) {
                printf("%g", a - b);
            } else if (strcmp(calc[1], "*") == 0) {
                printf("%g", a * b);
            } else if (strcmp(calc[1], "/") == 0) {
                if (b == 0) {
                    printf("Error: Division by zero.");
                } else {
                    printf("%g", a / b);
                }
            } else if (strcmp(calc[1], "^") == 0) {
                printf("%g", pow(a, b));
            } else if (strcmp(calc[1], "root") == 0) {
                printf("%g", pow(a, 1.0/b));
            } else {
                printf("Error: Operation not recognised or available.");
            }
            printf("\n");
        
        } else if (strcasecmp(DOS_statement, "OUT\n") == 0 || strcasecmp(DOS_statement, "OUT.PROG\n") == 0) {
            printf("Error: Missing parameters.\n");
        
        } else if (strcasecmp(DOS_statement, "OUT") == 0 || strcasecmp(DOS_statement, "OUT.PROG") == 0) {
            DOS_statement = strtok(NULL, "\n");
            if (DOS_statement == NULL) continue;
            if (strcasecmp(DOS_statement, "IO1") == 0) blink(IO1);
            else if (strcasecmp(DOS_statement, "IO2") == 0) blink(IO2);
            else if (strcasecmp(DOS_statement, "IO3") == 0) blink(IO3);
            else if (strcasecmp(DOS_statement, "LED1") == 0) blink(LED1);
            else if (strcasecmp(DOS_statement, "LED2") == 0) blink(LED2);
            else if (strcasecmp(DOS_statement, "LED3") == 0) blink(LED3);
            else if (strcasecmp(DOS_statement, "BELL") == 0) blink(BELL);
            else if (strcasecmp(DOS_statement, "MOTOR") == 0) blink(MOTOR);
            else printf("Error: Invalid GPIO pin number. Valid pins: IO1, IO2, IO3, LED1, LED2, LED3, BELL, MOTOR\n");
        
        } else if (strcasecmp(DOS_statement, "BOOT\n") == 0 || strcasecmp(DOS_statement, "BOOT.PROG\n") == 0) {
            printf("Rebooting...\n");
            main();
        
        } else if (strcasecmp(DOS_statement, "BOOT") == 0 || strcasecmp(DOS_statement, "BOOT.PROG") == 0) {
            char *reboot[3];
            for (int i=0; i<3; i++){
                DOS_statement = strtok(NULL, " ");
                if (DOS_statement != NULL) {
                    reboot[i] = strdup(DOS_statement);
                } else {
                    reboot[i] = 0;
                    break;
                }
            }
            if (strcasecmp(reboot[1], "BASIC\n") == 0) {
                printf("Rebooting to Macro Microcontroller BASIC...\n");
                mode = 1;
                main();
            } else if (strcasecmp(reboot[1], "BOOTSEL\n") == 0) {
                printf("Rebooting to BOOTSEL mode...\n");
                mode = 2;
                main();
            } else {
                printf("Error: Invalid option provided.\n");
            }
        
        } else if (strcasecmp(DOS_statement, "UPTIME\n") == 0 || strcasecmp(DOS_statement, "UPTIME.PROG\n") == 0) {
            printf("Uptime: %02u seconds\n", to_ms_since_boot(get_absolute_time())/1000);

        } else if (strcasecmp(DOS_statement, "EXIT\n") == 0) {
            return;
        } else {
            printf("Command or file does not exist.\n");
        }
    }
}

void blink(int pin) {
    gpio_put(pin, 1);
    sleep_ms(1000);
    gpio_put(pin, 0);
}

void interpreter() {
    mode = 0;
    printf("Macro Microcontroller BASIC Version 0.0.3.\n");
    volatile uint32_t stack_var;
    printf("%d bytes of RAM free.\n", (uint32_t)&stack_var - (uint32_t)&end);
    printf("Ready.\n");
    while (true) {
        line_count++;
        printf("%d0 ", line_count);
        memset(input, 0, 51);
        fgets(input, 51, stdin);
        printf("%s", input);
        char *statement = strtok(input, " ");
        if (statement == NULL) continue;
        if (strcasecmp(statement, "PRINT") == 0) {
            statement = strtok(NULL, "\n");
            if (statement == NULL) continue;
            if (strcasecmp(statement, variable[0]) == 0) {
                statement = variable[1];
                if (*statement == '"') {
                    statement++;
                    char *close = strrchr(statement, '"');
                    *close = '\0';
                }
                printf("%s\n", statement);
            } else if (*statement == '"') {
                statement++;
                char *close = strrchr(statement, '"');
                *close = '\0';
                printf("%s\n", statement);
            } else if (strcasecmp(statement, "BELL") == 0) {
                gpio_put(BELL, 1);
                sleep_ms(100);
                gpio_put(BELL, 0);
                printf("BELL\n");
            } else if (strcasecmp(statement, "RND") == 0) {
                printf("%f\n", (float)rand() / (float)RAND_MAX);
            }

        } else if (strcasecmp(statement, "GPIO") == 0) {
            statement = strtok(NULL, "\n");
            if (statement == NULL) continue;
            if (strcasecmp(statement, "IO1") == 0) blink(IO1);
            else if (strcasecmp(statement, "IO2") == 0) blink(IO2);
            else if (strcasecmp(statement, "IO3") == 0) blink(IO3);
            else if (strcasecmp(statement, "LED1") == 0) blink(LED1);
            else if (strcasecmp(statement, "LED2") == 0) blink(LED2);
            else if (strcasecmp(statement, "LED3") == 0) blink(LED3);
            else if (strcasecmp(statement, "BELL") == 0) blink(BELL);
            else if (strcasecmp(statement, "MOTOR") == 0) blink(MOTOR);
            else printf("Error: Invalid GPIO pin number. Valid pins: IO1, IO2, IO3, LED1, LED2, LED3, BELL, MOTOR\n");

        } else if (strcasecmp(statement, "INPUT") == 0) {
            statement = strtok(NULL, "\n");
            if (statement == NULL) continue;
            printf("%s? ", statement);
            fgets(user_input, 51, stdin);
            printf("%s", user_input);
            char *value = strtok(user_input, "\n");
            variable[0] = strdup(statement);
            variable[1] = value;

        } else if (strcasecmp(statement, "LET") == 0) {
            statement = strtok(NULL, " ");
            if (statement == NULL) continue;
            variable[0] = strdup(statement);
            statement = strtok(NULL, " ");
            statement = strtok(NULL, "\n");
            if (strcasecmp(statement, "RND") == 0) {
                char rndtext[8];
                sprintf(rndtext, "%.6f", (float)rand() / (float)RAND_MAX);
                variable[1] = rndtext;
            } else {
                variable[1] = strdup(statement);
            }

        } else if (strcasecmp(statement, "END\n") == 0) {
            variable[0] = "";
            variable[1] = "";
            line_count = 0;
            printf("Ready.\n");
            
        } else if (strcasecmp(statement, "EXIT\n") == 0) {
            variable[0] = "";
            variable[1] = "";
            line_count = 0;
            printf("\n");
            return;
        
        } else if (strcasecmp(statement, "LSVAR\n") == 0) {
            if (variable[0] != "") {
                printf("Variable %s ", variable[0]);
                printf("with value %s\n", variable[1]);
            }
            
        } else if (strcasecmp(statement, "REM") != 0) {
            printf("Error: Invalid statement.\n");

        }
    }
}

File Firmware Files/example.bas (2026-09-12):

10 REM SPDX-License-Identifier: CC0-1.0
20 REM Macro Microcontroller BASIC Example Program
30 REM Note: line numbers are automatically appended in the interpreter.
40 REM Please remove the numbers before running the program!

50 REM Example 1: Hello world!
60 PRINT "hello world!"
70 END

80 REM Example 2: Activate buzzer and motor
90 GPIO BELL
100 GPIO MOTOR
110 END

120 REM Example 3: Random floating-point number
130 PRINT RND
140 END

150 REM Example 4: Assigning variables
160 LET X = 5
170 LSVAR
180 END

190 REM Example 5: Reading input
200 INPUT Name
210 PRINT "Hello, "
220 PRINT Name
230 END

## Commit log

2026-06-20 Update enclosure for barrel jack
    [enclosure.stl]
2026-06-21 Update components
    [bom.csv, macro-microcontroller-2.kicad_pcb, macro-microcontroller-2.kicad_sch]
2026-06-21 Update schematics
2026-06-24 Update PCB
    [bom.csv, designators.csv, macro-microcontroller-2.kicad_pcb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]
2026-07-11 Add board image
2026-07-22 Modify schematics
2026-09-07 Update datasheet to include OS and change flash memory capacity
2026-11-11 Change BOM error

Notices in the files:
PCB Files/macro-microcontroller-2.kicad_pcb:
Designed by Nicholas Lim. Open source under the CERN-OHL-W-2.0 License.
